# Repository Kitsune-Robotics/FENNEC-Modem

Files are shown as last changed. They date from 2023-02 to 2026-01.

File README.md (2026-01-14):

# The Fennec Modem

A **F**lexible **E**xperimental **N**etwork for **N**ovel **E**lectronic **C**ommunication!

Hello and thank you for looking in here!

APRN is a combined pairing of bell202 from packet radio, with SSTV and other more analog formats. While never widely adopted, I always had a strong affection for the strange format! The inspiration for this format was originally recorded [here.](https://web.archive.org/web/20080328040214/http://web.usna.navy.mil/~bruninga/aprntxt.html)

The Fennec Modem is designed with APRN in mind! But is in no means only limted to that one format, any AFSK or similar audio/soundcard mode radio should be possible with this board!

 - [x] APRN
 - [x] Packet
 - [ ] APRS
 - [ ] Other SSTV Formats

# Getting started

Clone this repo

```shell
git clone --recurse-submodules https://github.com/Kitsune-Robotics/FENNEC-Modem
```

# Thank You!

Without the resources from other hams on the internet, I don't know if i would ever get this project done!

https://github.com/handiko/Dorji-TX-Shield
http://squirrelengineering.com/arduino/dra818v-aprs-144-390mhz/

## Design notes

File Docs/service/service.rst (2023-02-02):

Service
=======

This section is yet to be filled out!

Schematics
----------

Schematics for the Fennec Modem

Board Schematics

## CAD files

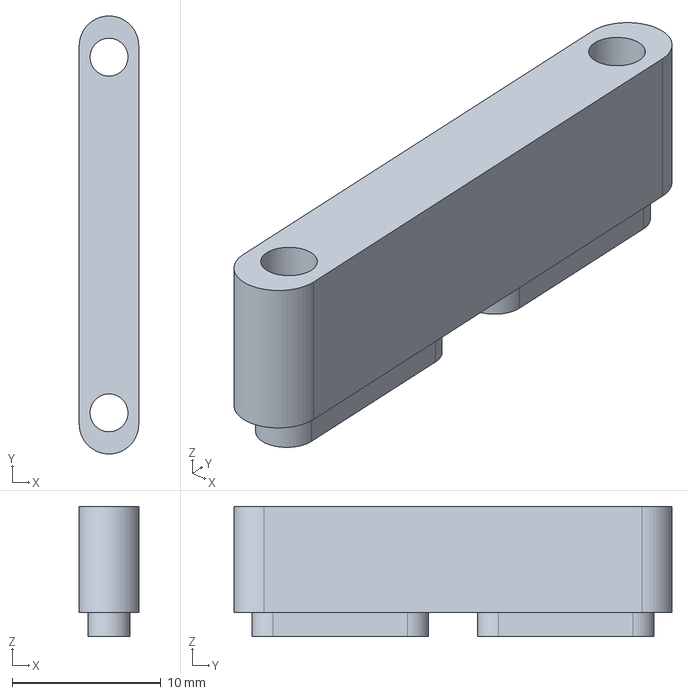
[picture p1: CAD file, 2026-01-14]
CAD/Fan Spacer.FCStd
4.00 x 29.4 x 8.74 mm

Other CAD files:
CAD/Fan Spacer-Fan Spacer.step

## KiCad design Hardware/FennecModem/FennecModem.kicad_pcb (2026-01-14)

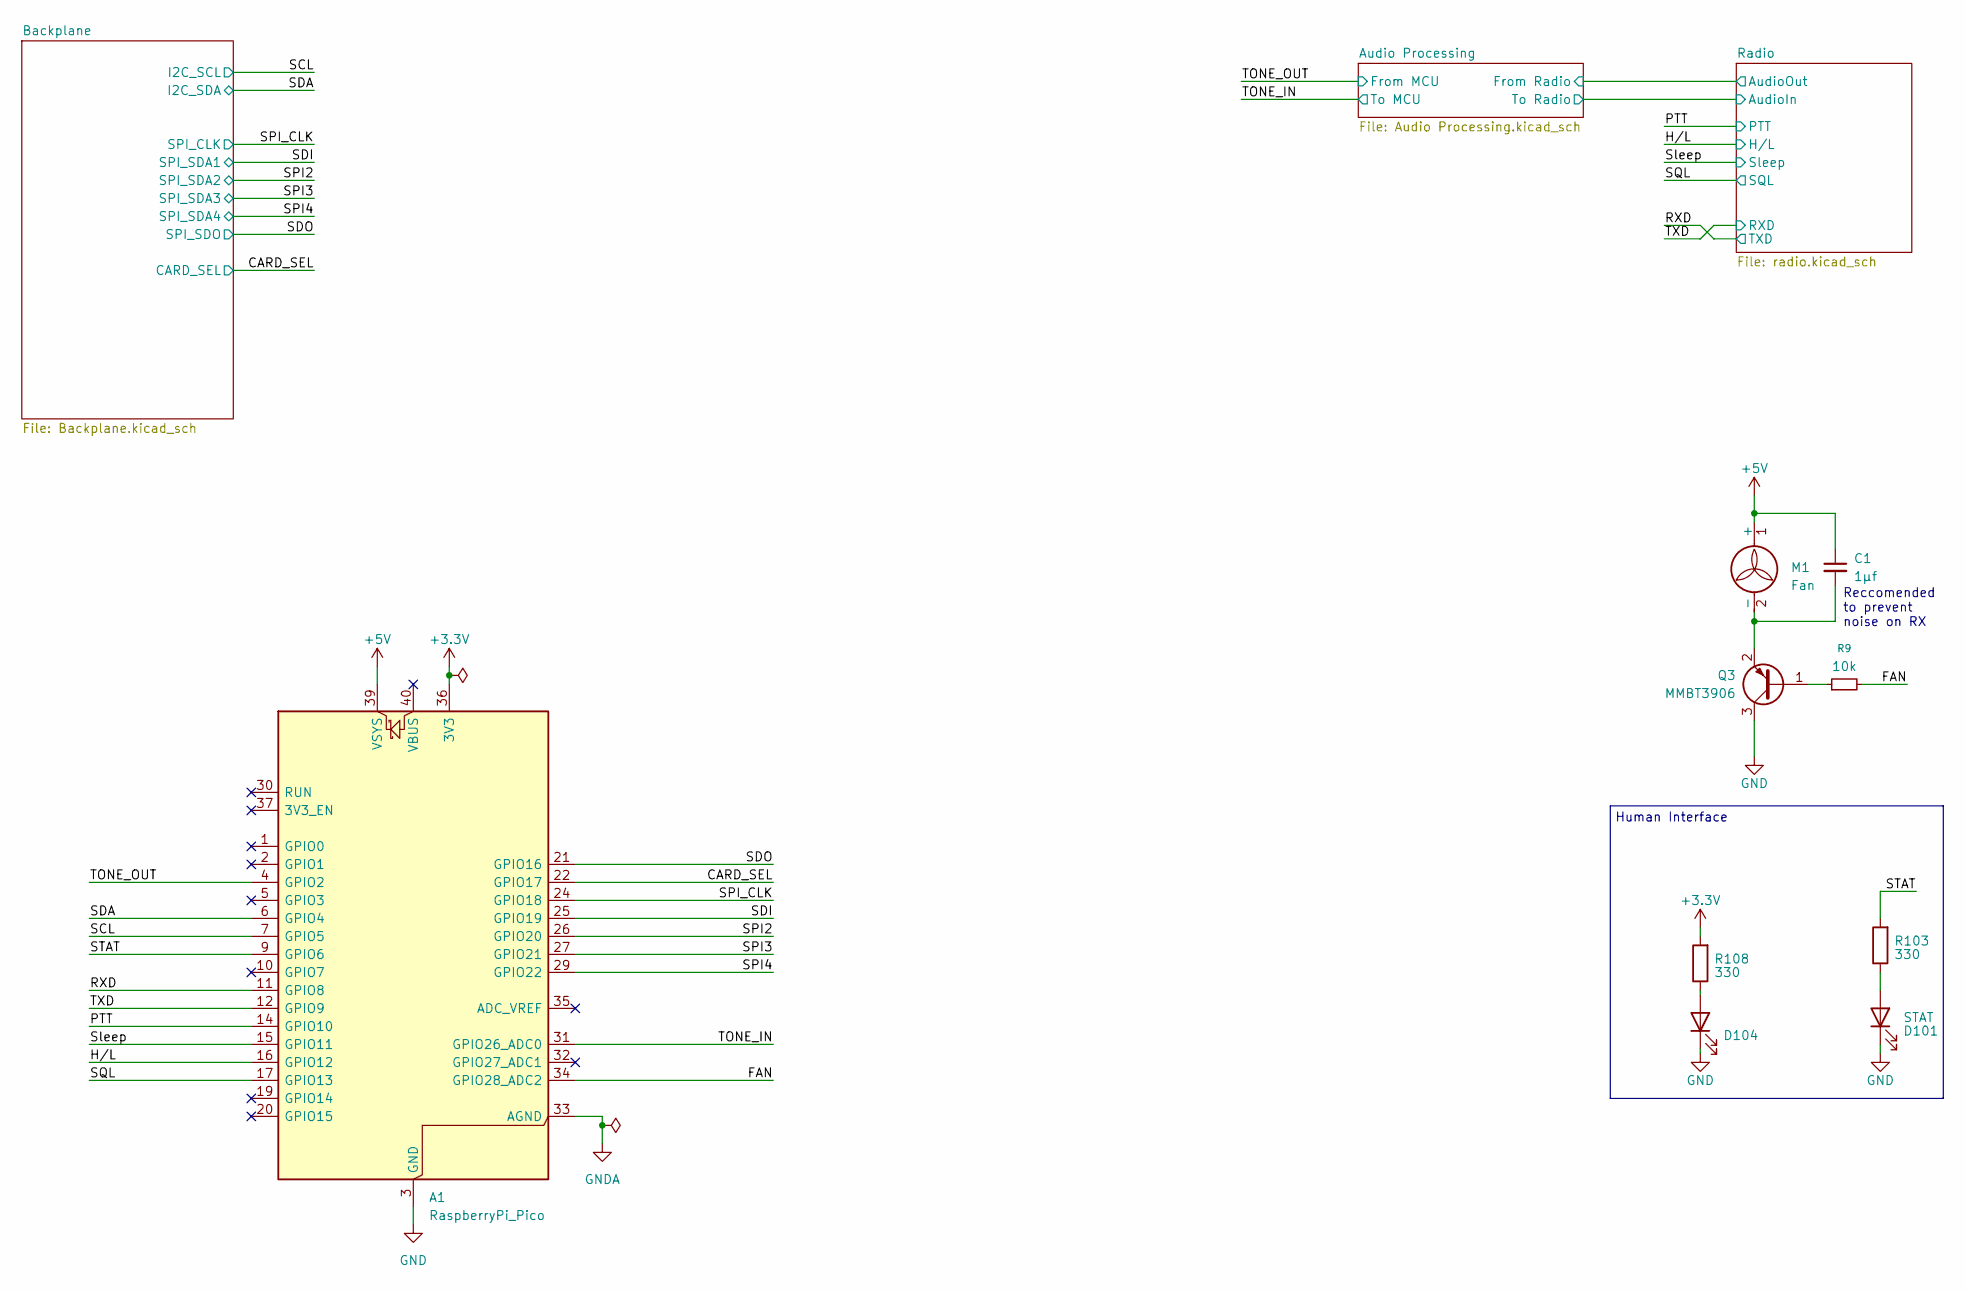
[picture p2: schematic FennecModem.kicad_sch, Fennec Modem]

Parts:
A1: RaspberryPi_Pico; RaspberryPi_Pico_Common_THT
C1: 1μf; C_0805_2012Metric
D101: STAT; LED_D3.0mm_Horizontal_O1.27mm_Z2.0mm
D104: PWR; LED_D3.0mm_Horizontal_O1.27mm_Z2.0mm
M1: Fan; JST_EH_B2B-EH-A_1x02_P2.50mm_Vertical
Q3: MMBT3906; SOT-23
R9: 10k; R_0805_2012Metric
R103, R108: 330; R_0805_2012Metric

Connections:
+3.3V: A1.36 (3V3), R108.2; also elsewhere on the board
+5V: A1.39 (VSYS), C1.1, M1.1 (+); also elsewhere on the board
/CARD_SEL: A1.22 (GPIO17); also elsewhere on the board
/FAN: A1.34 (GPIO28_ADC2), R9.2
/H/L: A1.16 (GPIO12); also elsewhere on the board
/PTT: A1.14 (GPIO10); also elsewhere on the board
/RXD: A1.11 (GPIO8); also elsewhere on the board
/SCL: A1.7 (GPIO5)
/SDA: A1.6 (GPIO4)
/SDI: A1.25 (GPIO19); also elsewhere on the board
/SDO: A1.21 (GPIO16); also elsewhere on the board
/SPI2: A1.26 (GPIO20); also elsewhere on the board
/SPI3: A1.27 (GPIO21); also elsewhere on the board
/SPI4: A1.29 (GPIO22); also elsewhere on the board
/SPI_CLK: A1.24 (GPIO18); also elsewhere on the board
/SQL: A1.17 (GPIO13); also elsewhere on the board
/STAT: A1.9 (GPIO6), R103.2
/Sleep: A1.15 (GPIO11); also elsewhere on the board
/TONE_IN: A1.31 (GPIO26_ADC0); also elsewhere on the board
/TONE_OUT: A1.4 (GPIO2); also elsewhere on the board
/TXD: A1.12 (GPIO9); also elsewhere on the board
GND: A1.3 (GND), A1.8 (GND), A1.13 (GND), A1.18 (GND), A1.23 (GND), A1.28 (GND), A1.38 (GND), D101.1 (K), D104.1 (K), Q3.3 (C); also elsewhere on the board
GNDA: A1.33 (AGND); also elsewhere on the board
unnamed: D101.2 (A), R103.1
unnamed: D104.2 (A), R108.1
unnamed: C1.2, M1.2 (-), Q3.2 (E)
unnamed: Q3.1 (B), R9.1

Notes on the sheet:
Reccomended to prevent noise on RX
Human Interface

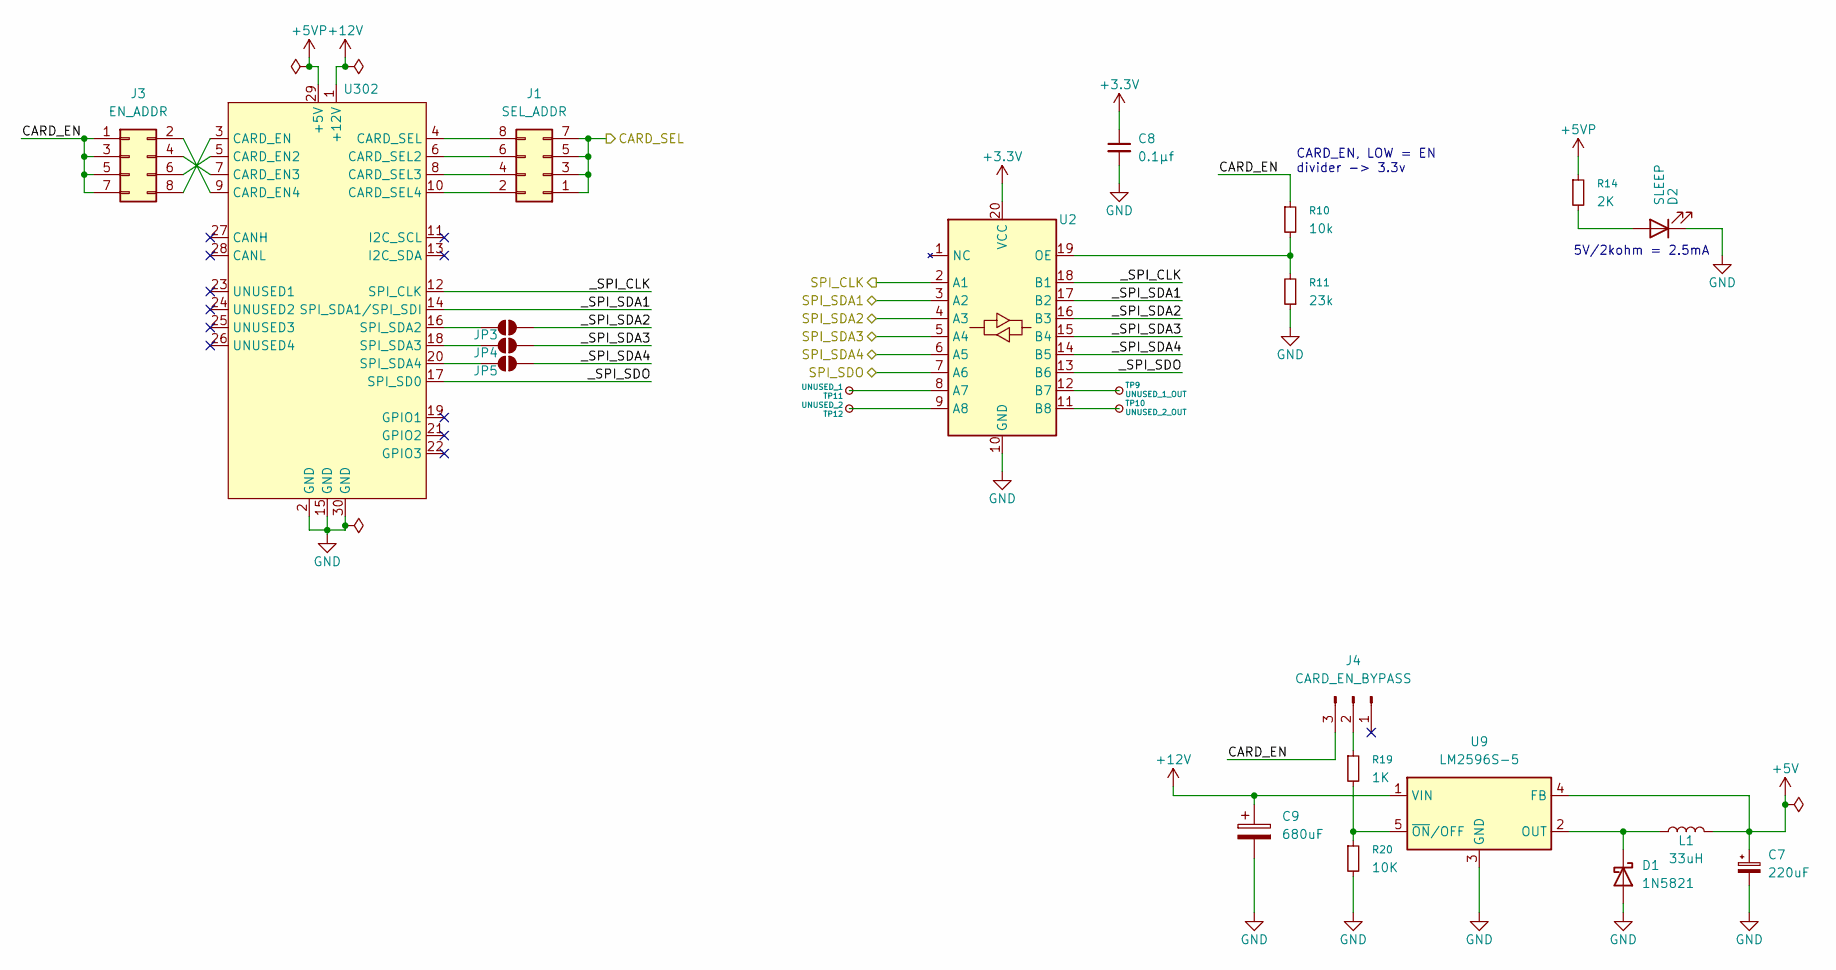
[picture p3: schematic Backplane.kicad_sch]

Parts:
C7: 220uF; CP_Radial_D5.0mm_P2.50mm
C8: 0.1μf; C_0805_2012Metric
C9: 680uF; CP_Radial_D10.0mm_P5.00mm
D1: 1N5821; D_DO-41_SOD81_P5.08mm_Vertical_AnodeUp; LCSC# C5295406
D2: SLEEP; LED_0805_2012Metric
J1: SEL_ADDR; PinHeader_2x04_P2.54mm_Vertical
J3: EN_ADDR; PinHeader_2x04_P2.54mm_Vertical
J4: CARD_EN_BYPASS; PinHeader_1x03_P2.54mm_Vertical
JP3, JP4, JP5: SolderJumper_2_Open; SolderJumper-2_P1.3mm_Open_TrianglePad1.0x1.5mm
L1: 33uH; L_6.3x6.3_H3
R10: 10k; R_0805_2012Metric
R11: 23k; R_0805_2012Metric
R14: 2K; R_0805_2012Metric
R19: 1K; R_0805_2012Metric
R20: 10K; R_0805_2012Metric
TP9: UNUSED_1_OUT; TestPoint_Bridge_Pitch2.0mm_Drill0.7mm
TP10: UNUSED_2_OUT; TestPoint_Bridge_Pitch2.0mm_Drill0.7mm
TP11: UNUSED_1; TestPoint_Bridge_Pitch2.0mm_Drill0.7mm
TP12: UNUSED_2; TestPoint_Bridge_Pitch2.0mm_Drill0.7mm
U2: SN74CBTLV3245A; SSOP-20_3.9x8.7mm_P0.635mm; LCSC# C2878923
U9: LM2596S-5; TO-263-5_TabPin3; LCSC# C116713
U302: Lewis_Card_Connector

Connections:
+3.3V: C8.1, U2.20 (VCC); also elsewhere on the board
+5V: C7.1, L1.2, U9.4 (FB); also elsewhere on the board
+5VP: R14.1, U302.29 (+5V)
+12V: C9.1, U9.1 (VIN), U302.1 (+12V)
/Backplane/CARD_EN: J3.1, J3.3, J3.5, J3.7, J4.3, R10.1
/Backplane/_SPI_CLK: U2.18 (B1), U302.12 (SPI_CLK)
/Backplane/_SPI_SDA1: U2.17 (B2), U302.14 (SPI_SDA1/SPI_SDI)
/Backplane/_SPI_SDA2: JP3.1 (A), U2.16 (B3)
/Backplane/_SPI_SDA3: JP4.1 (A), U2.15 (B4)
/Backplane/_SPI_SDA4: JP5.1 (A), U2.14 (B5)
/Backplane/_SPI_SDO: U2.13 (B6), U302.17 (SPI_SD0)
/CARD_SEL: J1.1, J1.3, J1.5, J1.7; also elsewhere on the board
/SDI: U2.3 (A2); also elsewhere on the board
/SDO: U2.7 (A6); also elsewhere on the board
/SPI2: U2.4 (A3); also elsewhere on the board
/SPI3: U2.5 (A4); also elsewhere on the board
/SPI4: U2.6 (A5); also elsewhere on the board
/SPI_CLK: U2.2 (A1); also elsewhere on the board
GND: C7.2, C8.2, C9.2, D1.2 (A), D2.1 (K), R11.1, R20.2, U2.10 (GND), U9.3 (GND), U302.2 (GND), U302.15 (GND), U302.30 (GND); also elsewhere on the board
unnamed: D1.1 (K), L1.1, U9.2 (OUT)
unnamed: D2.2 (A), R14.2
unnamed: J1.2, U302.10 (CARD_SEL4)
unnamed: J1.4, U302.8 (CARD_SEL3)
unnamed: J1.6, U302.6 (CARD_SEL2)
unnamed: J1.8, U302.4 (CARD_SEL)
unnamed: J3.2, U302.9 (CARD_EN4)
unnamed: J3.4, U302.7 (CARD_EN3)
unnamed: J3.6, U302.5 (CARD_EN2)
unnamed: J3.8, U302.3 (CARD_EN)
unnamed: J4.2, R19.1
unnamed: JP3.2 (B), U302.16 (SPI_SDA2)
unnamed: JP4.2 (B), U302.18 (SPI_SDA3)
unnamed: JP5.2 (B), U302.20 (SPI_SDA4)
unnamed: TP11.1, U2.8 (A7)
unnamed: TP12.1, U2.9 (A8)
unnamed: TP9.1, U2.12 (B7)
unnamed: TP10.1, U2.11 (B8)
unnamed: R10.2, R11.2, U2.19 (OE)
unnamed: R19.2, R20.1, U9.5 (~ON/OFF)

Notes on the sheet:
5V/2kohm = 2.5mA
CARD_EN, LOW = EN divider -> 3.3v

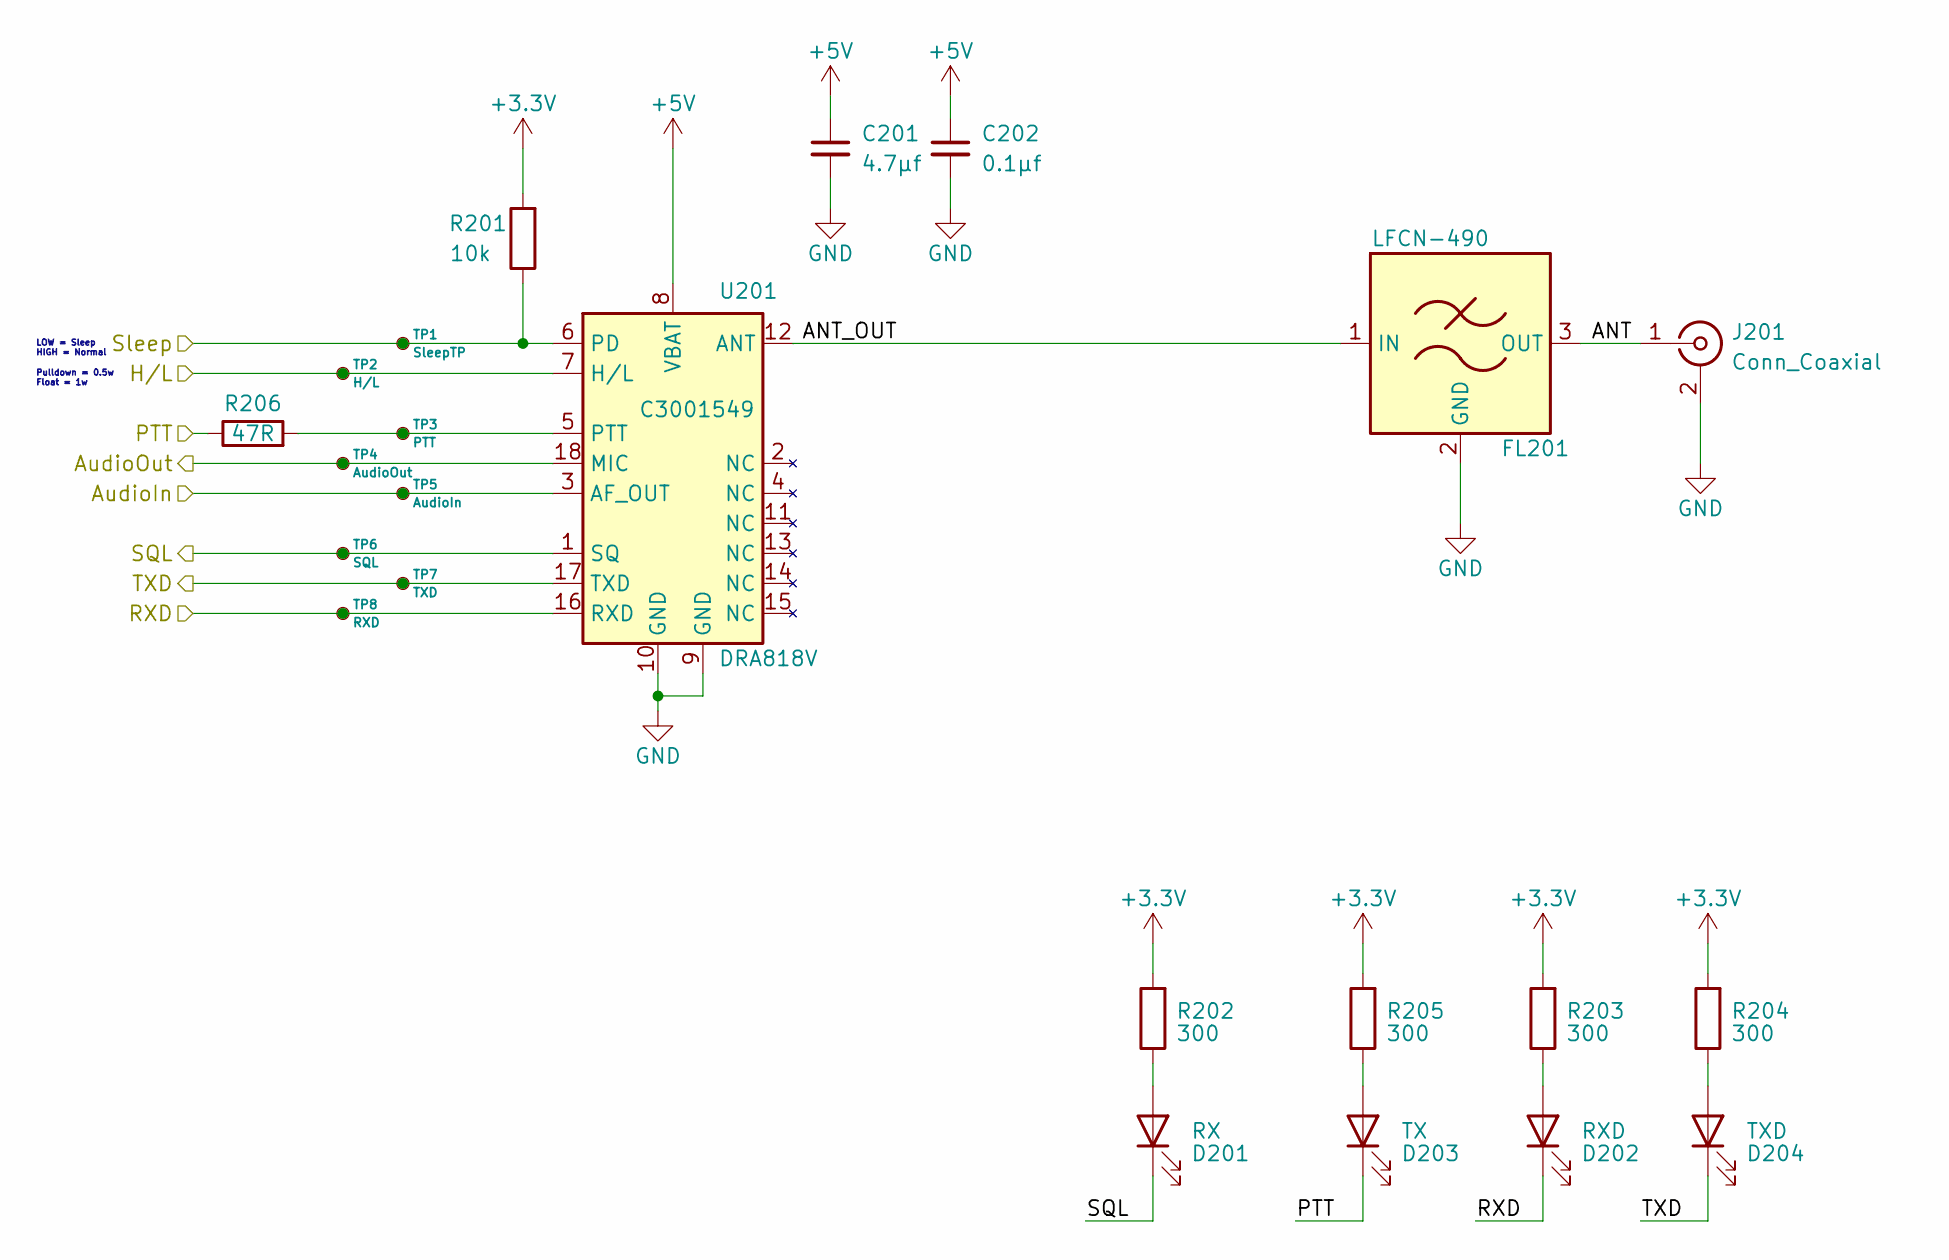
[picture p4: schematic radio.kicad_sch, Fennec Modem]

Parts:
C201: 4.7μf; C_0805_2012Metric
C202: 0.1μf; C_0805_2012Metric
D201: RX; LED_D3.0mm_Horizontal_O1.27mm_Z2.0mm
D202: RXD; LED_0805_2012Metric
D203: TX; LED_D3.0mm_Horizontal_O1.27mm_Z2.0mm
D204: TXD; LED_0805_2012Metric
FL201: LFCN-490; Filter_Mini-Circuits_FV1206
J201: Conn_Coaxial; SMA_Amphenol_132289_EdgeMount
R201: 10k; R_0805_2012Metric
R202, R203, R204, R205: 300; R_0805_2012Metric
R206: 47R; R_0805_2012Metric
TP1: SleepTP; TestPoint_Bridge_Pitch2.0mm_Drill0.7mm
TP2: H/L; TestPoint_Bridge_Pitch2.0mm_Drill0.7mm
TP3: PTT; TestPoint_Bridge_Pitch2.0mm_Drill0.7mm
TP4: AudioOut; TestPoint_Bridge_Pitch2.0mm_Drill0.7mm
TP5: AudioIn; TestPoint_Bridge_Pitch2.0mm_Drill0.7mm
TP6: SQL; TestPoint_Bridge_Pitch2.0mm_Drill0.7mm
TP7: TXD; TestPoint_Bridge_Pitch2.0mm_Drill0.7mm
TP8: RXD; TestPoint_Bridge_Pitch2.0mm_Drill0.7mm
U201: DRA818V; LCSC# C3001549

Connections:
+3.3V: R201.2, R202.2, R203.2, R204.2, R205.2; also elsewhere on the board
+5V: C201.1, C202.1, U201.8 (VBAT); also elsewhere on the board
/Audio Processing/From Radio: TP4.1, U201.18 (MIC); also elsewhere on the board
/Audio Processing/To Radio: TP5.1, U201.3 (AF_OUT); also elsewhere on the board
/H/L: TP2.1, U201.7 (H/L); also elsewhere on the board
/PTT: D203.1 (K), R206.1; also elsewhere on the board
/RXD: D204.1 (K), TP7.1, U201.17 (TXD); also elsewhere on the board
/Radio/ANT: FL201.3 (OUT), J201.1 (In)
/Radio/ANT_OUT: FL201.1 (IN), U201.12 (ANT)
/SQL: D201.1 (K), TP6.1, U201.1 (SQ); also elsewhere on the board
/Sleep: R201.1, TP1.1, U201.6 (PD); also elsewhere on the board
/TXD: D202.1 (K), TP8.1, U201.16 (RXD); also elsewhere on the board
GND: C201.2, C202.2, FL201.2 (GND), FL201.4 (GND), J201.2 (Ext), U201.9 (GND), U201.10 (GND); also elsewhere on the board
unnamed: D201.2 (A), R202.1
unnamed: D202.2 (A), R203.1
unnamed: D203.2 (A), R205.1
unnamed: D204.2 (A), R204.1
unnamed: R206.2, TP3.1, U201.5 (PTT)

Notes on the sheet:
Pulldown = 0.5w Float = 1w
LOW = Sleep HIGH = Normal

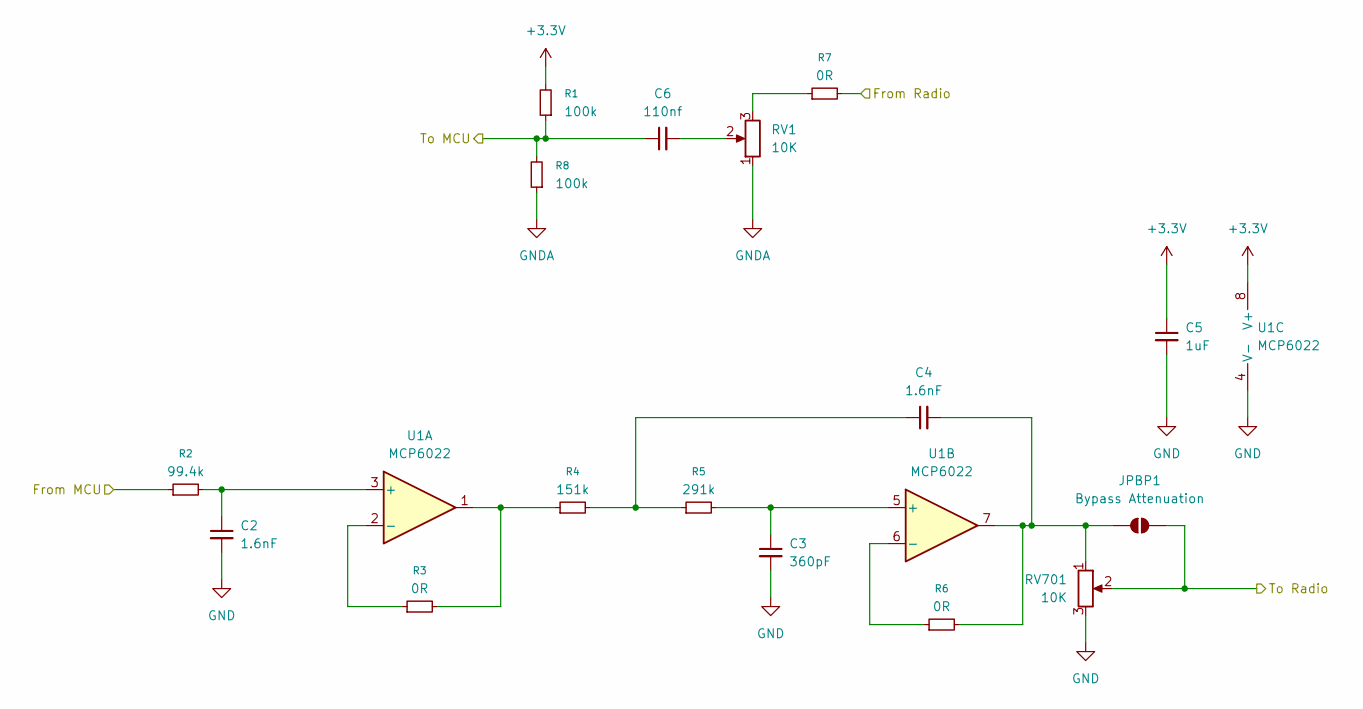
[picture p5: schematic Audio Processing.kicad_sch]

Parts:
C2, C4: 1.6nF; C_0805_2012Metric
C3: 360pF; C_0805_2012Metric
C5: 1uF; C_0805_2012Metric
C6: 110nf; C_0805_2012Metric
JPBP1: Bypass Attenuation; SolderJumper-2_P1.3mm_Open_TrianglePad1.0x1.5mm
R1, R8: 100k; R_0805_2012Metric
R2: 99.4k; R_0805_2012Metric
R3, R6, R7: 0R; R_0805_2012Metric
R4: 151k; R_0805_2012Metric
R5: 291k; R_0805_2012Metric
RV1, RV701: 10K; Potentiometer_Bourns_TC33X_Vertical
U1: MCP6022; SOIC-8_3.9x4.9mm_P1.27mm; LCSC# C57639

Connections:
+3.3V: C5.1, R1.2, U1.8 (V+); also elsewhere on the board
/Audio Processing/From Radio: R7.2; also elsewhere on the board
/Audio Processing/To Radio: JPBP1.2 (B), RV701.2; also elsewhere on the board
/TONE_IN: C6.1, R1.1, R8.2; also elsewhere on the board
/TONE_OUT: R2.1; also elsewhere on the board
GND: C2.2, C3.2, C5.2, RV701.3, U1.4 (V-); also elsewhere on the board
GNDA: R8.1, RV1.1; also elsewhere on the board
unnamed: C4.1, R4.2, R5.1
unnamed: C6.2, RV1.2
unnamed: C4.2, JPBP1.1 (A), R6.2, RV701.1, U1.7
unnamed: R3.2, R4.1, U1.1
unnamed: R7.1, RV1.3
unnamed: C2.1, R2.2, U1.3 (+)
unnamed: R3.1, U1.2 (-)
unnamed: C3.1, R5.2, U1.5 (+)
unnamed: R6.1, U1.6 (-)

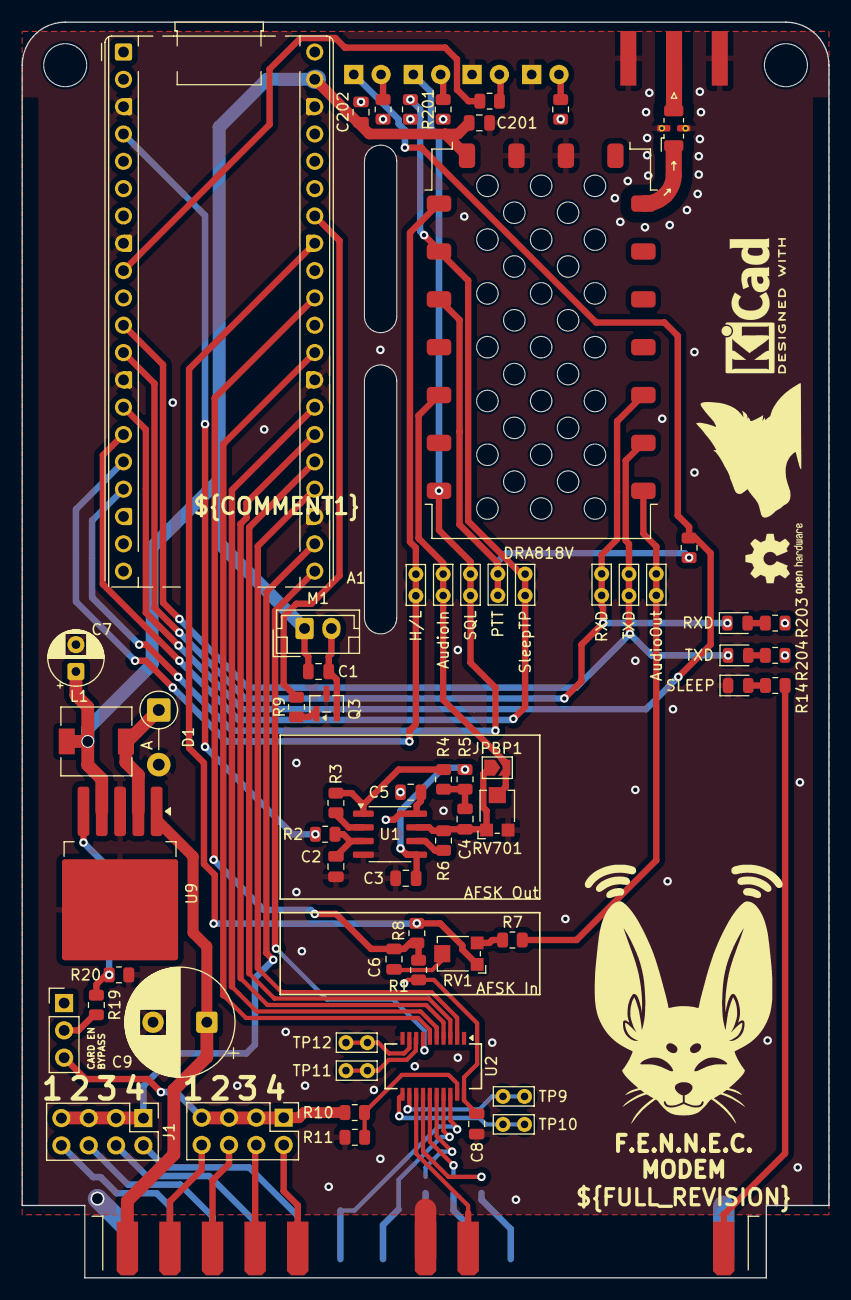
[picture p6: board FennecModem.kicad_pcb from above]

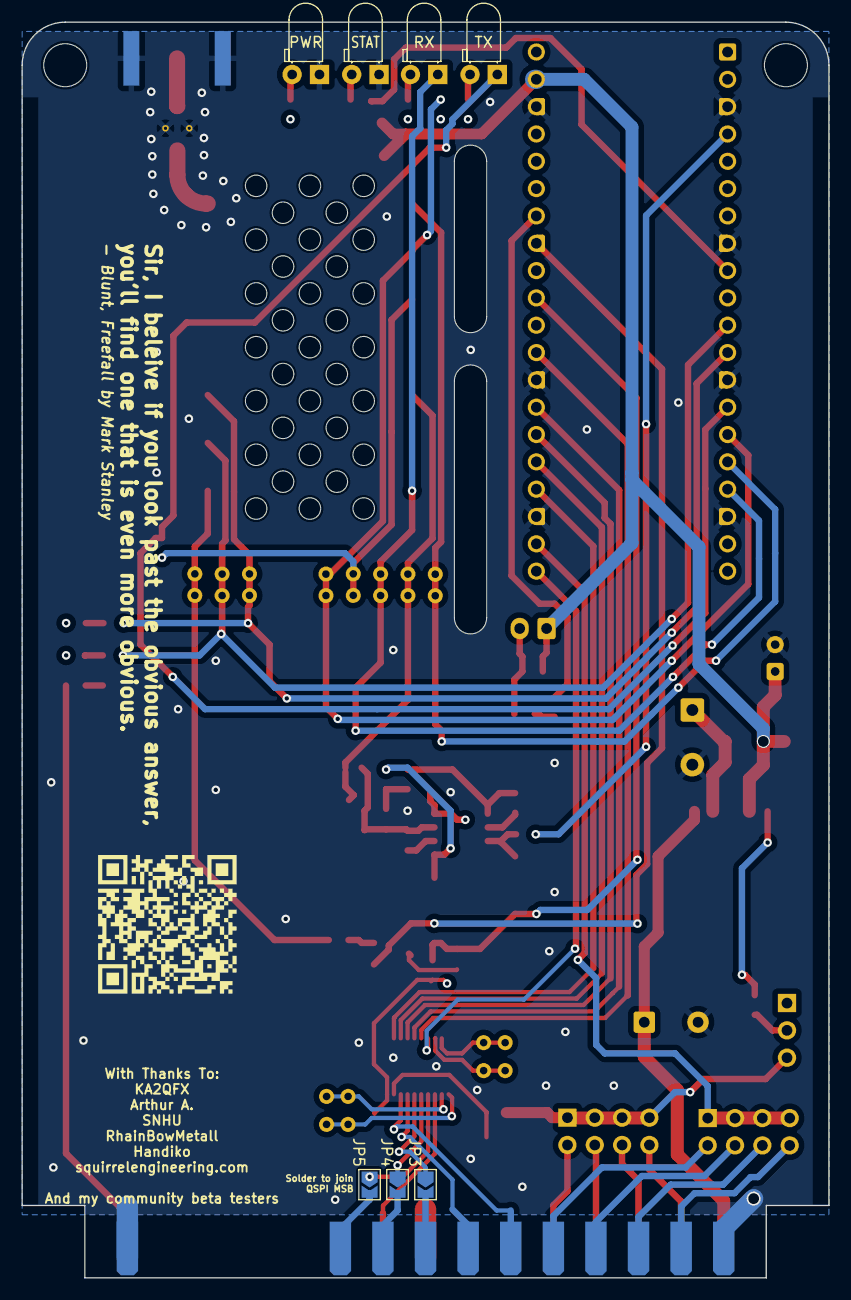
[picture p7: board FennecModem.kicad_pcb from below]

Board: 4 copper layers, 75.0 x 116.7 mm, 73 parts (7 on the bottom side), 72 nets.

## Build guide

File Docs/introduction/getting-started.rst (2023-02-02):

Getting Started
===============

Introduction
------------

.. 
..   :width: 80%
..   :alt: Initial Render

Welcome! This section is yet to be filled out.

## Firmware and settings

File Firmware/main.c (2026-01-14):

#include <stdio.h>
#include "pico/stdlib.h"
#include "shift_register_display.h"

// Shift register pin configuration
#define DIN_PIN 18    // Data input pin
#define CLK_PIN 17    // Clock pin  
#define LATCH_PIN 16  // Latch pin

// Square wave generation pin
#define SQUARE_WAVE_PIN 2  // Could be any pin really

int main() {
    // Initialize stdio for USB output
    stdio_init_all();
    
    // Configure display pins
    display_config_t display_config = {
        .din_pin = DIN_PIN,
        .clk_pin = CLK_PIN,
        .latch_pin = LATCH_PIN
    };
    
    // Initialize the display
    if (display_init(&display_config) != 0) {
        printf("Failed to initialize display!\n");
        return -1;
    }

    // Initialize square wave pin
    gpio_init(SQUARE_WAVE_PIN);
    gpio_set_dir(SQUARE_WAVE_PIN, GPIO_OUT);
    gpio_put(SQUARE_WAVE_PIN, 0);

    // Boot animation on the 7-segment display
    display_boot_animation(100);
    
    // Clear the display after animation
    display_clear();
    
    // Critical frequencies for slow scan
    const uint32_t frequencies[] = {900, 1200, 2400, 2800, 2900, 3000};
    const uint32_t num_frequencies = sizeof(frequencies) / sizeof(frequencies[0]);
    uint32_t current_freq_index = 0;
    
    // Calculate initial half period for first frequency (900 Hz)
    uint32_t current_frequency = frequencies[current_freq_index];
    uint32_t half_period_us = 1000000 / (2 * current_frequency);  // microseconds
    
    printf("Starting with frequency: %d Hz (half period: %d us)\n", 
           current_frequency, half_period_us);
    
    absolute_time_t last_freq_change = get_absolute_time();
    uint32_t iteration = 0;
    
    while (true) {
        // Check if 10 seconds have passed to change frequency
        if (absolute_time_diff_us(last_freq_change, get_absolute_time()) >= 10000000) {
            current_freq_index = (current_freq_index + 1) % num_frequencies;
            current_frequency = frequencies[current_freq_index];
            half_period_us = 1000000 / (2 * current_frequency);
            last_freq_change = get_absolute_time();
            
            printf("Switching to frequency: %d Hz (half period: %d us)\n", 
                   current_frequency, half_period_us);
            display_set_digit(current_freq_index);
        }
        
        // Generate current frequency square wave
        gpio_put(SQUARE_WAVE_PIN, 1);
        sleep_us(half_period_us);
        gpio_put(SQUARE_WAVE_PIN, 0);
        sleep_us(half_period_us);
        
        // Toggle the decimal point every 1000 iterations 
        if (iteration % 1000 == 0) {
            display_toggle_decimal_point();
        }
        
        iteration++;
    }
    
    return 0;
}

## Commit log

2023-02-02 Boilerplate from kw1fox-2
    [FennecModem.kicad_pcb, FennecModem.kicad_sch]
2023-02-02 Add kenwoodfox libs
    [FennecModem.kicad_sch]
2023-02-02 Inital Docs
    [FennecModem.kicad_pcb, FennecModem.kicad_sch, cm108adc-dac.kicad_sch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]
2023-02-09 Add modem components, bump edge card connector in upstream
    [FennecModem.kicad_sch, radio.kicad_sch, usbserial.kicad_sch]
2023-02-10 F*ck yeah edge connectors!
    [FennecModem.kicad_pcb, FennecModem.kicad_sch, radio.kicad_sch]
2023-02-10 Add more
    [FennecModem.kicad_pcb, FennecModem.kicad_sch, radio.kicad_sch]
2023-02-10 Bump kenwoodfox libs
    [FennecModem.kicad_pcb]
2023-11-28 Inital Backplane (#1)
    Inital backplane is done, another PR can be opened later for more advanced stuff.
    [BackPlane.kicad_pcb, BackPlane.kicad_sch, Backplane.kicad_sch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]
2026-01-14 Tones (#2)
    [Audio Processing.kicad_sch, Audio Simulation.sch, BackPlane.kicad_pcb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]
2026-01-14 Adjsut some final silkscreen
    [FennecModem.kicad_pcb]
